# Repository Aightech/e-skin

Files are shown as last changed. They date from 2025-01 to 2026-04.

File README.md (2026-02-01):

# E-Skin

A bioinspired electronic skin system for robotic applications, combining FSR (force-sensing resistor) arrays and accelerometer arrays.

## Overview

The electronic board uses two multiplexers and two 16-channel ADCs to read the FSRs. The multiplexers select the row or column of the FSR array, while the ADCs read the sensor values. A Teensy 4.1 controls the multiplexers and ADCs and sends data to the computer via USB or Ethernet.

**Operation modes:**
- **Single mode**: Connect one FSR array with up to 32x32 sensors
- **Dual mode**: Connect two FSR arrays with up to 16x16 sensors each

**Sampling rate:** ~400 KHz/channel (1562.5 Hz for a 16x16 array)

## Project Structure

```
e-skin/
├── host/           # C++/Qt host application
│   ├── src/        # Source code (main.cpp)
│   └── lib/        # Git submodules (com_client, built_lsl)
├── src/            # Teensy firmware
│   └── Eskin/      # Main production firmware
├── models/         # KiCAD PCB designs
│   ├── KiCAD/              # Main control board (MUX + ADC)
│   ├── customSquare16x16/  # 16x16 FSR array
│   ├── customSquare8x8/    # 8x8 FSR array
│   ├── LIS2DH_array/       # LIS2DH accelerometer array
│   ├── KX134_array/        # KX134 accelerometer array
│   └── inskinacc/          # In-skin accelerometer
└── script/         # Python/MATLAB data acquisition scripts
```

## Requirements

### Host Application
- CMake 3.3+
- Qt6 (Core, Widgets, PrintSupport)
- C++11 compiler

### Firmware
- Arduino IDE or PlatformIO
- Teensy 4.1 board support

### Python Scripts
- Python 3.x
- Dependencies: `pip install -r script/requirements.txt`

## Building

### Host Application

```bash
cd host
mkdir build && cd build
cmake .. && make
./FSR_array -h  # Show usage
```

### Firmware

Upload `src/Eskin/Eskin.ino` to Teensy 4.1 using Arduino IDE or PlatformIO.

- Board: Teensy 4.1
- Port: `/dev/ttyACM0` (Linux) or `COMx` (Windows)

### Python Data Recorder

```bash
pip install -r script/requirements.txt
python script/record.py <port> <array_size>
# Example: python script/record.py /dev/ttyACM0 16
```

## Communication Protocol

- **Serial**: 500000 baud
- **Ethernet**: TCP port 5000
- **Command format**: 1 byte (2 MSB = mode, 6 LSB = array size)
  - Mode 0: Request 1 FSR array
  - Mode 1: Request 2 FSR arrays
  - Mode 2: Request 1 ACC array
  - Mode 3: Request 1 ACC array + 2 FSR arrays
- **Response**: 4-byte timestamps + uint16_t sensor data

## Submodule Dependencies

- [built_lsl](host/lib/built_lsl/README.md) - Lab Streaming Layer integration
- [com_client](host/lib/com_client/README.md) - Serial/TCP communication library

Initialize submodules:
```bash
git submodule update --init --recursive
```

## Example

See [main.cpp](host/src/main.cpp) for an example of how to use the communication library.

## Contributing

See [CONTRIBUTING.md](CONTRIBUTING.md) for details on our code of conduct and the process for submitting pull requests.

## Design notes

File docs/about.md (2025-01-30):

---
layout: page
title: About
---

# About the Soft e-Skin Project

Our **Soft e-Skin** initiative explores how bioinspired layered sensors—mimicking the human skin’s multiple layers and multimodal receptors—can be applied to robotics and beyond. By embedding force-sensing and vibration-sensing devices in silicone, we seek to develop robust, adaptable tactile sensors suited for a wide range of applications.

We believe in:
- **Open collaboration** – sharing ideas, data, and designs.
- **Ease of replication** – using off-the-shelf components and straightforward fabrication.
- **Future-proof design** – ensuring our approach scales up to larger areas and higher sensor densities.

Our research group

## Meet the Team

- **A. W. M. Devillard** – Lead design of silicone encapsulation and FSR layers.
- **A. Dutta** – Electronics and embedded systems architect.
- **Z. Zhang** – Data processing, including neural networks for force/vibration analysis.
- **X. Cheng** – Materials specialist and sensor fabrication advisor.
- **M. Kaboli** – Industrial applications and integration with commercial robotics.
- **E. Burdet** – Principal investigator, overseeing overall system design and research direction.

## Our Vision

1. **Enhanced Haptic Intelligence**  
   We aim to enable robots and prostheses with skin-like sensing, providing advanced interaction awareness for safer, more dextrous manipulation.

2. **Customisable Layers**  
   Different thicknesses, materials, or sensor arrays can be easily swapped in or out, broadening the e-skin’s utility in varied tasks (medical, exploratory, industrial, etc.).

3. **Multimodal Research**  
   Beyond forces and vibrations, future expansions may include temperature, proximity, or chemical sensors—pushing the boundaries of what “electronic skin” can detect.

---

Need more details or fancy giving it a try? Head to the **[tutorial](/tutorial)** page for build instructions or see our **[article](/article)** for technical results. 

We look forward to collaborating with fellow researchers and enthusiasts—do get in touch if you’d like to share your ideas or feedback!

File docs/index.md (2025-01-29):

---
layout: page
title: "Home"
---

# Welcome

Thiiis is the home page for our _Modular and Scalable Soft e-Skin_ project. We draw inspiration from the layered structure of human skin to create a sensor array that can measure both normal and shear forces as well as vibrations in robotic applications. Our approach emphasises:

- **Modularity** – Easy to add or remove layers and sensors.
- **Scalability** – Straightforward to expand the sensor arrays with simplified electronics.
- **Accessibility** – Employing off-the-shelf components and standard silicone moulding.

Have a look at our **[project summary](/article)** for the main technical details, or head directly to the **[tutorial page](/tutorial)** to build your own!

Comparison of human skin structure and bioinspired e-skin design

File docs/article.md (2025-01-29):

---
layout: post
title: "Summary"
date: 2025-01-29
author: "A. W. M. Devillard, A. Dutta, Z. Zhang, X. Cheng, M. Kaboli, E. Burdet"
---

E-skin layers diagram

## Abstract

The human skin is a complex system playing several roles in everyday life. Not only does it sense the environment, it also protects the body. To build a bioinspired haptic sensor, the density and type of sensors are important, but one must also consider the skin’s mechanical properties and overall robustness. 

In this study, we present a bioinspired **modular and scalable** design of a soft electronic skin (e-skin) to investigate the role of the skin's mechanical attributes in tactile sensing for robotic applications. We characterise and evaluate our system using objects with varied mechanical properties, showing how our e-skin can capture both forces and vibrations and differentiate between objects of different stiffness or surface textures.

---

## 1. Introduction

Research in haptic sensing aims to replicate the richness of human touch in robotic end-effectors, prostheses, and more. Human skin’s dermis and epidermis contain multiple receptors detecting pressure, vibration, and temperature. By mimicking this layered approach with modern soft materials and off-the-shelf sensors, we can produce large-area, flexible e-skins that provide normal and shear force measurements as well as high-frequency vibration data.

**Key Features:**
- **Layered Silicone Encapsulation:** Inspired by epidermis and dermis.
- **Multimodal Sensing:** Force-sensing resistors (FSRs) for normal and shear, accelerometers for vibration.
- **Scalable Electronics:** A multiplexed design reduces wiring complexity.

Kinova robot with e-skin

---

## 2. Design & Fabrication

### 2.1 Layered Structure

1. **Top Silicone Layer:** Acts like an epidermis, protecting internal sensors.
2. **Accelerometer Layer:** A small-array PCB for vibration detection.
3. **Inter-layer Silicone:** Adds compliance to allow slight shear displacements.
4. **FSR Layers:** Two stacked 16×16 FSR arrays to measure normal pressures but also infer shear forces.
5. **Base Silicone:** Final protective layer.

### 2.2 Electronics

- **Accelerometers:** SPI-based array with demultiplexers to manage up to 16 devices on minimal lines.
- **FSRs:** Each 16×16 array read by scanning 16 row lines and 16 column lines. 
- **Microcontroller:** A Teensy 4.1 capturing up to 800 Hz from all sensors, streaming data via USB.

---

## 3. Experiments

We mounted the e-skin onto a Kinova robotic arm equipped with a 6-axis force/torque sensor. We tested interactions (pressing, rolling, slipping) against a series of ‘wave objects’ featuring different stiffnesses and surface textures. Our aim was to see how well the e-skin could estimate normal and shear forces, and classify objects by texture and compliance.

---

## 4. Results and Discussion

- **Force Estimation:** The two FSR layers and compliant silicone enable basic shear reconstruction (X-Y), plus normal force (Z).
- **Object Classification:** Combining force and vibration data in a neural network yields clear separation of soft vs. rigid objects, and differentiates surfaces with different spatial frequencies.

### Future Directions
Ongoing improvements involve reconfigurable sensor densities, adding temperature or humidity sensors, and adapting the silicone’s thickness/hardness for varied tasks.

---

## References

1. Howe, R., & Cutkosky, M. "Tactile sensing and control of robotic manipulation." *Advanced Robotics*, 1993.  
2. Kim, D., et al. "Highly sensitive tactile sensors using microstructured dielectrics." *Advanced Materials*, 2012.  
3. Chen, X., et al. "Self-powered flexible pressure sensors with ZnO nanowires." *Nano Energy*, 2015.

And others…

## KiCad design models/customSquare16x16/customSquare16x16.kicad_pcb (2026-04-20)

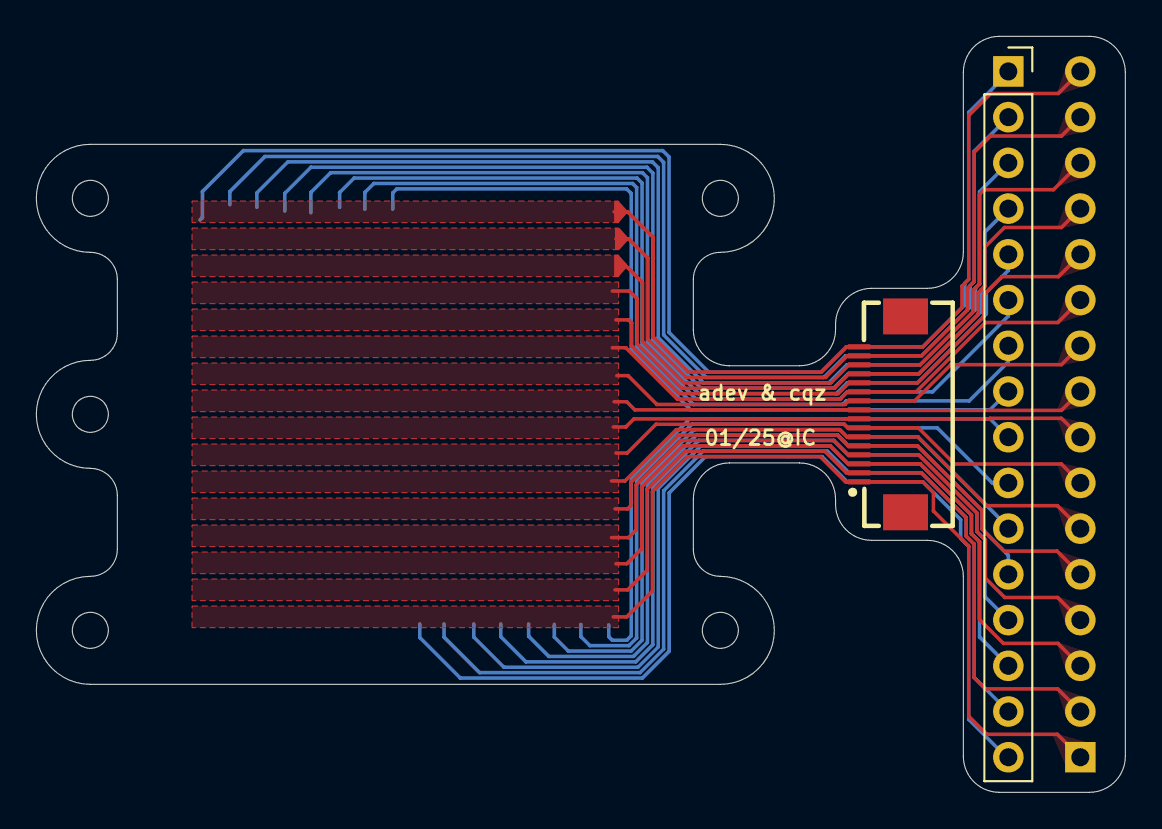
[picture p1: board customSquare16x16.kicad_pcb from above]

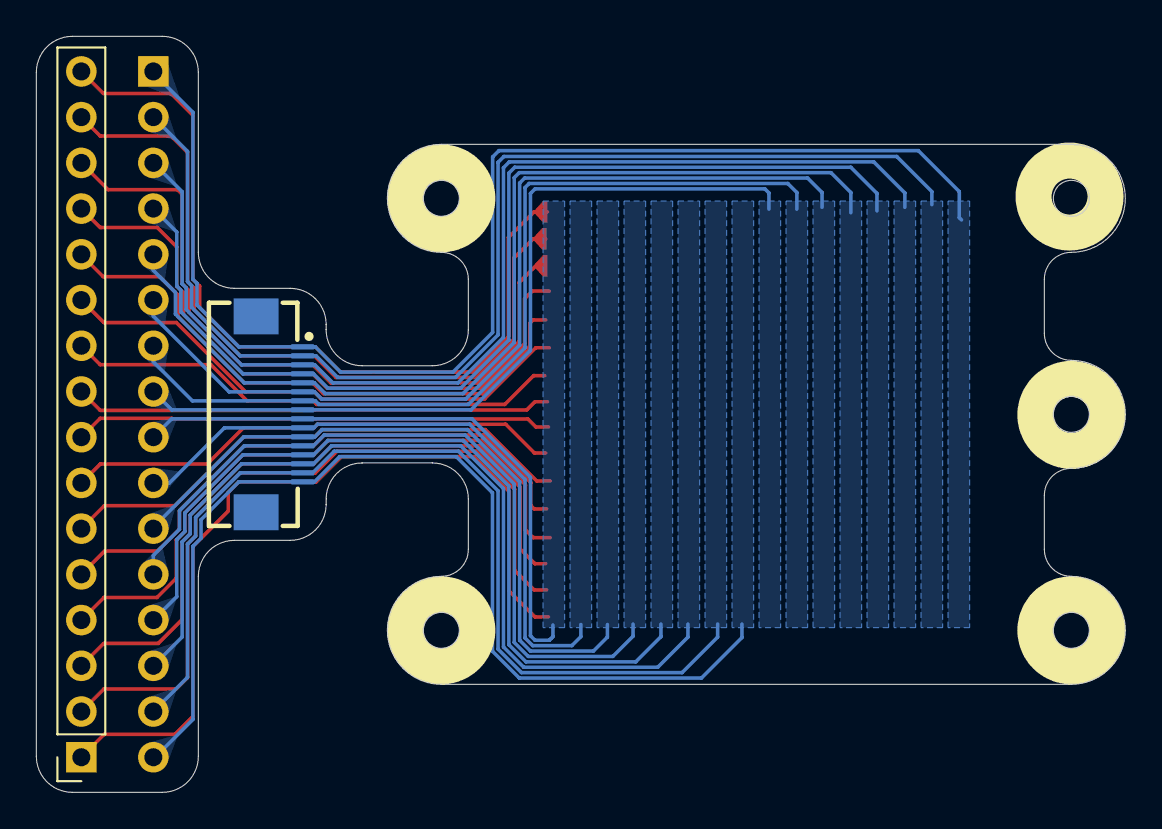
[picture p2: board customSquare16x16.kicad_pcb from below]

Board: 2 copper layers, 60.5 x 42.0 mm, 4 parts (2 on the bottom side), 32 nets.

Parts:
FPC1, FPC2: FPC-05F-16PH20; FPC-SMD_16P-P0.50_FPC-05F-16PH20
J1, J2: Conn_01x16_Pin; PinSocket_1x16_P2.54mm_Vertical

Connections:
/ain0: FPC2.1, J2.1
/ain1: FPC2.2, J2.2
/ain2: FPC2.3, J2.3
/ain3: FPC2.4, J2.4
/ain4: FPC2.5, J2.5
/ain5: FPC2.6, J2.6
/ain6: FPC2.7, J2.7
/ain7: FPC2.8, J2.8
/ain8: FPC2.9, J2.9
/ain9: FPC2.10, J2.10
/ain10: FPC2.11, J2.11
/ain11: FPC2.12, J2.12
/ain12: FPC2.13, J2.13
/ain13: FPC2.14, J2.14
/ain14: FPC2.15, J2.15
/ain15: FPC2.16, J2.16
/out0: FPC1.1, J1.1
/out1: FPC1.2, J1.2
/out2: FPC1.3, J1.3
/out3: FPC1.4, J1.4
/out4: FPC1.5, J1.5
/out5: FPC1.6, J1.6
/out6: FPC1.7, J1.7
/out7: FPC1.8, J1.8
/out8: FPC1.9, J1.9
/out9: FPC1.10, J1.10
/out10: FPC1.11, J1.11
/out11: FPC1.12, J1.12
/out12: FPC1.13, J1.13
/out13: FPC1.14, J1.14
/out14: FPC1.15, J1.15
/out15: FPC1.16, J1.16

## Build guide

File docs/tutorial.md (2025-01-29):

---
layout: page
title: "Tutorial"
---

# How to Make the E-Skin

This tutorial covers the step-by-step fabrication and assembly process, including a short video demonstration. You’ll need:

- **Materials:** Smooth-On Ecoflex or DragonSkin, 3D-printed moulds, force-sensing resistor (FSR) arrays, accelerometers (LIS3DH or similar), flexible PCBs.
- **Tools:** 3D printer, soldering iron, small oven or hot air station (optional), mixing scales.

Silicone mould and FSR arrays

---

## 1. Creating the Silicone Layers

1. **Print or prepare your mould:** Ensure the internal dimensions accommodate the sensor arrays.  
2. **Mix silicone:** Follow the manufacturer’s instructions (e.g. 1:1 ratio by weight).  
3. **Pour a thin base:** This becomes your “outer layer.”  
4. **Cure:** Let the silicone cure fully (time depends on product, typically 2–4 hours).

---

## 2. Placing the Sensors

1. **Position FSR Arrays:** Gently set one 16×16 array onto the partially cured silicone.  
2. **Add a second thin silicone pour:** This partially encapsulates the first FSR layer.  
3. **Place the second FSR layer:** Ensure alignment with the first layer.  
4. **Accelerometer Array:** Lay or mount the small boards near the top side, bridging them to the main PCB.  

Accelerometer layer on flexible PCB

---

## 3. Wiring and Electronics

1. **Solder the demultiplexers and ADCs** to a control PCB (or breadboard).  
2. **Connect the FSR rows/columns** and accelerometer chip-select lines.  
3. **Use a Teensy 4.1** (or similar) for high-speed acquisition.  
4. **Check your data rate:** We aim for 800 Hz sampling across all sensors.

---

## 4. Final Encapsulation

1. **Top Silicone Pour:** Once all sensors are in place, pour the final layer.  
2. **Degas:** If you have a vacuum chamber, remove air bubbles for a cleaner finish.  
3. **Cure Thoroughly:** Follow the recommended cure schedule so everything sets properly.

---

## Video Demonstration

Below is a link to a demonstration video. Click the thumbnail to watch:

Video of e-skin build process (https://www.youtube.com/watch?v=VIDEO_ID)

*(Replace `VIDEO_ID` with the actual YouTube video ID.)*

---

## 5. Testing

Once built, test the e-skin by pressing or brushing against different objects. If you have a robotic arm, mount the e-skin on the end-effector with a bracket or other fixture, and check real-time data streams from your microcontroller.

**We hope you enjoy making your own e-skin!** 

Feel free to return to our **[Home page](/)** or read the **[Project Summary](/article)**.

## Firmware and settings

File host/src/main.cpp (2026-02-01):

#include <iostream>
#include <lsl_cpp.h>
#include <serial_client.hpp>
#include <stdio.h>
#include <stdlib.h>
#include <string.h>
#include <tcp_client.hpp>
#include <unistd.h>

#include <chrono>

int
main(int argc, char **argv)
{
    Communication::Client *device;

    if(0)
    {
        std::string path = "/dev/ttyACM0";
        device = new Communication::Serial();
        try
        {
            std::cout << "Com Interface:" << std::endl;
            device->open_connection(path.c_str(), 115200, O_RDWR | O_NOCTTY);
        }
        catch(std::string msg)
        {
            std::cout << "ERROR: " << msg << "\n";
            return 0;
        }
    }
    else
    {
        std::string path = "192.168.127.254";
        device = new Communication::TCP(2);
        try
        {
            device->open_connection(path.c_str(), 5000, 2);
        }
        catch(std::string msg)
        {
            std::cout << "ERROR: " << msg << "\n";
            return 0;
        }
    }

    usleep(2000000);

    int n_width = 16;
    int n_layer = 2;
    char cmd = n_width + (n_layer - 1) * 0x80;
    int nb_channel = n_width * n_width * n_layer;
    uint16_t data[nb_channel];
    uint32_t timestamps[2];

    lsl::stream_info info_sample("FSR", "sample", nb_channel, 0, lsl::cf_int16);
    lsl::stream_outlet outlet_sample(info_sample);
    std::vector<int16_t> sample(nb_channel);
    std::cout << "[INFOS] Now sending data... " << std::endl;

    int n = 0;
    uint32_t dt = 1000;
    for(int j = 0;; j++)
    {
        //compute the time for each loop
        //auto start = std::chrono::high_resolution_clock::now();
        n = device->writeS(&cmd, 1);
        //int32_t prev_t = timestamps[0];
        n = device->readS((uint8_t *)&timestamps, 2 * 4, false);
        // std::cout << "timestamps: " << timestamps[1] - timestamps[0] << " "
        //           << timestamps[0] - prev_t << std::endl;

        n = device->readS((uint8_t *)&data, nb_channel * 2, false);
        //std::cout << "nb data read: " << n<< std::endl;
        //std::cout << "nb data read: " << data[0] << " " << data[1] << std::endl;

        for(int i = 0; i < nb_channel; i++) { sample[i] = data[i]; }
        outlet_sample.push_sample(sample);

        //auto stop = std::chrono::high_resolution_clock::now();
        // auto duration =
        //     std::chrono::duration_cast<std::chrono::microseconds>(stop - start);
        // dt = (dt * (j + 1) + duration.count()) / (j + 2);
        // std::cout << "loop time: " << dt << std::endl;
    }

    return 0;
}

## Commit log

2026-02-01 Update README with comprehensive documentation
    Add project structure, requirements, firmware upload instructions,
    Python script usage, and communication protocol details. Fix broken
    markdown link syntax.
    [CMakeConfig.txt]
2026-04-20 chore: rewrite .gitignore and stop tracking build artifacts
    Rewrite the whitelist-based .gitignore to:
    - add /host to the whitelist (it was fully ignored by /*)
    - drop stale root entries (bin, include, lib, tool_lib, CMakeLists.txt, etc.)
    - switch subtree whitelists from !/dir/* to !/dir/** so nested files are kept
    - re-ignore generated content inside whitelisted subtrees:
    build/, venv/, __pycache__, *.pyc, *-backups/, fp-info-cache,
    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
2026-04-20 models(customSquare16x16): update PCB and project
    [customSquare16x16.kicad_pcb]
2026-04-20 models(yl16x16): add p1 and p2 PCB projects
    New 16x16 FSR panel variants (yl16x16_p1, yl16x16_p2) with schematics,
    layouts, KiCAD project files, flex configuration, and fabrication jobset.
    Generated outputs (plots/, jlcpcb/, backups, fp-info-cache) are excluded
    by .gitignore.
    [yl16x16_p1.kicad_pcb, yl16x16_p1.kicad_sch, yl16x16_p2.kicad_pcb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]
2026-04-20 docs: add CLAUDE.md and MUXEDADC plot2.py
    - CLAUDE.md: project guidance for Claude Code (build commands, code
    style, architecture overview)
    - src/MUXEDADC/plot2.py: live-plot variant for the muxed ADC sketch
2026-05-07 springy model
    [springy.kicad_pcb, springy.kicad_sch]
